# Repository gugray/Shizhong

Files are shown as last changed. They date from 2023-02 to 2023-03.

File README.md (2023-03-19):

# Remarkably Accurate Quartz Clock

This repository has all the code and design files for the Remarkably Accurate Quartz Clock
[documented on Hackaday](https://hackaday.io/project/190063-remarkably-accurate-quartz-clock).

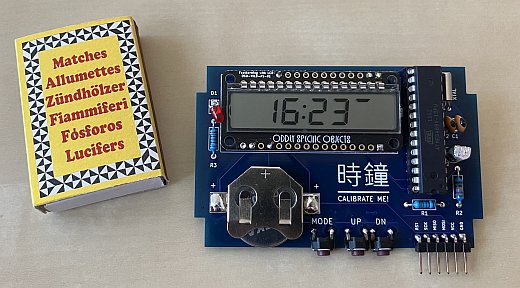
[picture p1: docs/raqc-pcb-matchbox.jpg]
The clock's circuit board, with a matchbox for scale

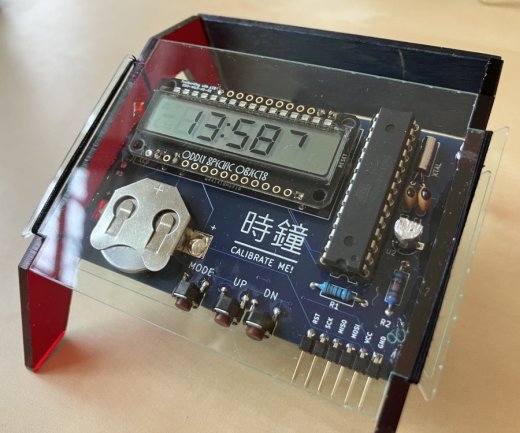
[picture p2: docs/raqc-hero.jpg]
The built-up clock in its laser-cut acrylic case


Can I use cheap, everyday components and build a quartz clock that beats specialized RTCs and matches the best commercial timepieces? Let's find out!

32kHz quartz crystals typically have a ±20ppm (parts per million) frequency tolerance, which translates to drift potentially in excess of 10 minutes per year. Specialized RTCs like DS3231 promise ±2ppm, or about ±1 minute per year.

RAQC aims for drift below 10 seconds per year. To achieve this, it implements fine-grained frequency correction in software. It has a screen to adjust time with subsecond precision, and it measures the temperature at 10-minute intervals to compensate for dynamic drift. After calibrating repeatedly at incresingly long intervals, RAQC knows the crystal's static error with a 0.01ppm precision.

Energy-saving programming techniques and a low-power LCD display keep the clock's current draw under 15μA, promising 1.5 years of uptime on a CR2032 coin cell.

## Electronics

The KiCad 5.1.9 schematic and PCB are in [/electronics](electronics). The ZIP file there is the Gerber export that I submitted to the PCB fab.

## Laser-cut frame

The frame is laser-cut from 3mm acryclic; the top and bottom covers are 1mm transparent acrylic. The front panel with the engraved overview of the clock's menu is laser-cut from 2mm birch.
The vector files for this are in [/design](design). The .ai file is the original, but I included a version re-saved as Inkscape .svg as well.

## Source code

The source code is in [/code/board](code/board). I developed it using the [PlatformIO extension](https://platformio.org/install/ide?install=vscode) for Visual Studio Code, so if you want to explore the code and build it yourself, that might be the easiest way to get started. The code uses the Arduino framework. It has only one dependency, the Wire library for I2C communication.

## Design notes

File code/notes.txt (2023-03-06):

TO-DO
=====================================
OK fine-tune by manipulating TCNT0
OK measure temp
OK faces neatly
OK periodic temp measurement
OK whole static correction shebang
   OK apply correction
   OK omit too-short time
   OK store and load from EEPROM
OK critical section around totalSeconds?
OK verify current draw
OK Fix extra beat issue in period
OK Time face: only loop function; ENTER event
OK BUG: set time screen times out on seconds
   OK timeout in seconds, not the quick timer
OK temperature-based dynamic corrections
OK design & order board v1
OK new screen on set: T0
OK don't re-measure temp on measure face
-- measure and eval green & red LED effect and current
-- battery voltage screen
?? calibration length screen?

To consider:
-- LED light button somewhere?
-- hours elapsed screen in tune face
-- do we need temperature screen? maybe midtemp calibration instead? do both fit?
-- do we need calibration history? its own screen?

Batery capacity ballpark
=====================================
CR2032 conservative capacity: 200mAh
At 50uA:  4000h, or 23 weeks
At 20uA: 10000h, or 59 weeks
At 15uA: 13333h, or 79 weeks ~ 1.5 years 
CR2: 800mAh
At 50uA: 16000h, or 95 weeks

Baseline sleep cycle, with no LCD update: 12.5uA
Spikes to ~40uA for update

Power draw with sleep to IDLE and no LCD refresh, Timer 0 as default: 400uA
Strangely, turning off Timer 0 only brings it down to 396uA
With my Timer0: 600uA

Temperature measurement
At 10 bits, DS18B20 takes 187ms -> 200ms
Active current max 1.5mA
At a 10-minute cadence: .2s out of 600s: 0.0005 mA equivalent: 0.5uA
This is not counting CPU draw during OneWire comms, but that's very quick

Experiment with 4700uF cap + 100k or 10k resistor: 14.3uA
-> this didn't catch temp measurement, so previous estimate of 0.5uA comes on top

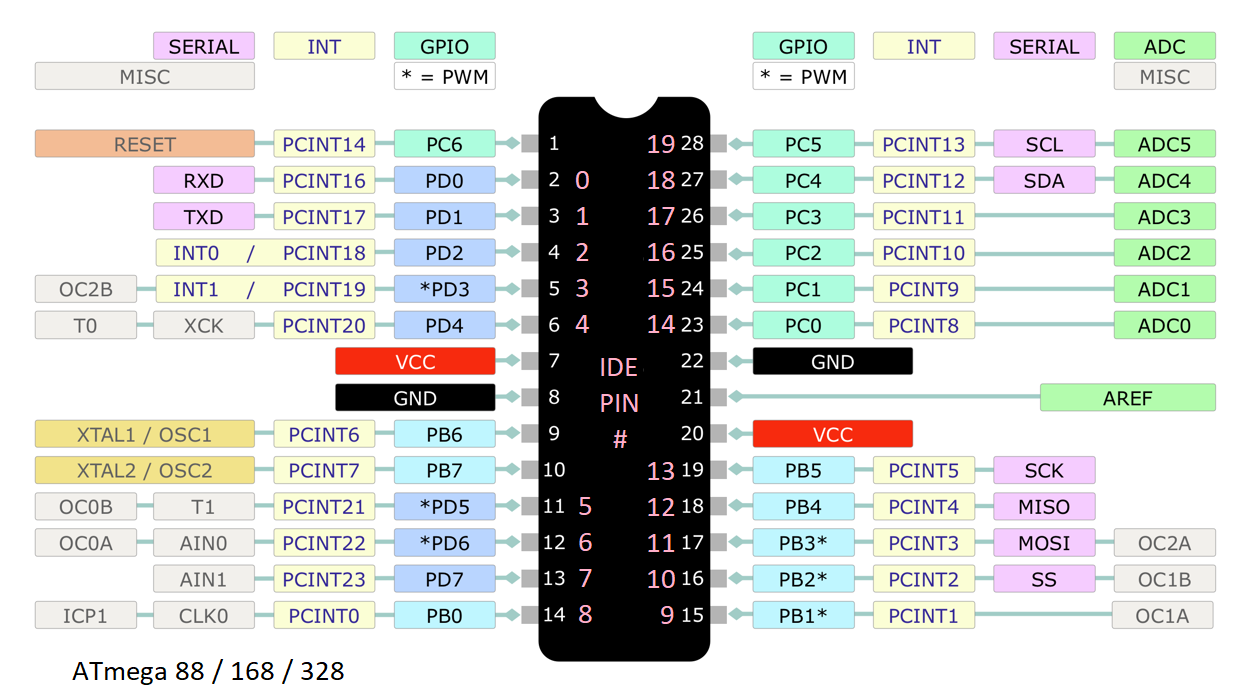
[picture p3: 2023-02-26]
docs/ATmega-88-pinout.png

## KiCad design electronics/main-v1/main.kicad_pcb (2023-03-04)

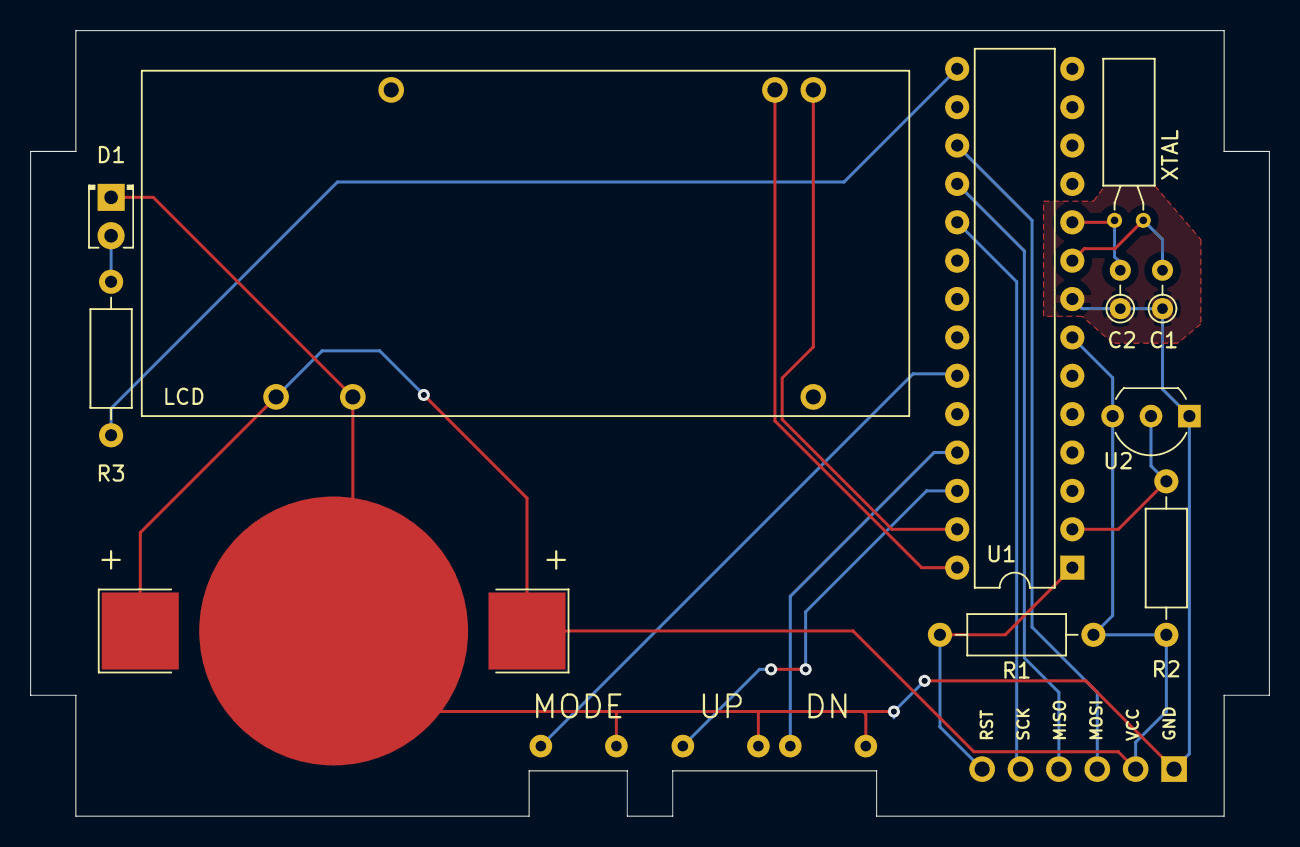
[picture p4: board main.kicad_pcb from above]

Board: 2 copper layers, 82.0 x 52.0 mm, 15 parts (0 on the bottom side), 16 nets.

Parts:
BT1: 3V Coin; BatteryHolder_Keystone_3002_1x2032
C1, C2: 6pF; R_Axial_DIN0204_L3.6mm_D1.6mm_P2.54mm_Vertical
D1: LED; LED_D2.0mm_W4.0mm_H2.8mm_FlatTop
J1: Port; PinHeader_1x06_P2.54mm_Vertical
LCD: LCD_Feather
R1: 10k; R_Axial_DIN0207_L6.3mm_D2.5mm_P10.16mm_Horizontal
R2: 5k; R_Axial_DIN0207_L6.3mm_D2.5mm_P10.16mm_Horizontal
R3: 1k; R_Axial_DIN0207_L6.3mm_D2.5mm_P10.16mm_Horizontal
SW1, SW2, SW3: SW_Push; PushButton5mm
U1: ATmega88V-10PU; DIP-28_W7.62mm
U2: DS18B20; TO-92_Inline_Wide
XTAL: 32kHz; Crystal_C38-LF_D3.0mm_L8.0mm_Horizontal

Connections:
GND: BT1.2, C1.1, C2.1, D1.1, J1.1, LCD.2, SW1.2, SW2.2, SW3.2, U1.8, U2.1
unnamed: C1.2, U1.9, XTAL.2
unnamed: C2.2, U1.10, XTAL.1
unnamed: D1.2, R3.2
unnamed: R3.1, U1.15
PIN-BTN-MINUS: SW2.1, U1.25
PIN-BTN-MODE: SW1.1, U1.23
PIN-BTN-PLUS: SW3.1, U1.26
PIN-DQ: R2.1, U1.2, U2.2
PIN-MISO: J1.4, U1.18
PIN-MOSI: J1.3, U1.17
PIN-RST: J1.6, R1.2, U1.1
PIN-SCK: J1.5, U1.19
PIN-SCL: LCD.4, U1.28
PIN-SDA: LCD.3, U1.27
VCC: BT1.1, J1.2, LCD.1, R1.1, R2.2, U1.7, U2.3

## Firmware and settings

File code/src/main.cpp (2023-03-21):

#include <Arduino.h>
#include "globals.h"
#include "events.h"
#include "DS18B20.h"
#include "persistence.h"
#include "time_face.h"
#include "tune_face.h"
#include "measure_face.h"
#include "lib/corrector.h"

// Definitions of globals vvv
// ==============================================

OSO_LCD lcd;
Time time;
Time prevTime;
uint32_t lastAdjustedAt = 0;
volatile uint32_t totalSeconds = 0;
volatile int16_t periodStartTemp = 0x7fff;
volatile int16_t latestMeasuredTemp;
volatile bool faceNeedsQuickTick = false;
volatile uint16_t counter0 = 0;
volatile uint8_t timer2Adjust = 0;
volatile uint8_t dsState = 0;

// Local vars vvv
// ==============================================

volatile uint16_t wakeEventMask = 0;
volatile uint16_t periodCounter = 0;

typedef uint8_t (*faceLoopFun)(uint16_t);

// 0: time; 1: tune; 2: measure
volatile uint8_t faceIx = 0;

const faceLoopFun loopFuns[] = {
    TimeFace::loop,
    TuneFace::loop,
    MeasureFace::loop,
};

const uint8_t nFaces = sizeof(loopFuns) / sizeof(faceLoopFun);

volatile bool timer0Running = false;
volatile uint16_t btnModePressedAt = 0xffff;
volatile uint16_t btnPlusPressedAt = 0xffff;
volatile uint16_t btnMinusPressedAt = 0xffff;

// Space for temp sensor's scratchpad
uint8_t dsData[9];

// Forward declarations of local functions vvv
// ==============================================

void stopTimer0();
void setupTimer0();
void setupTimer2();
void setupButtons();
void setupLowPower();
void goToSleep();
void configureTempSensor();
void startTempConversion();
void readTemp();

// Setup and loop: high-level control
// ==============================================

void setup()
{
  digitalWrite(LED_PIN, LOW);
  pinMode(LED_PIN, OUTPUT);

  Corrector::setStaticError(Persistence::loadStaticError());
  int16_t t0 = Persistence::loadCrystalT0();
  if (t0 != 0)
    Corrector::setCrystalT0(t0);

  lcd.begin();

  // Call time face's enter at startup, so we have meaningful content on display immediately
  loopFuns[0](EVT_ENTER_FACE);

  configureTempSensor();
  stopTimer0();
  setupButtons();
  setupTimer2();
  setupLowPower();

  dsState = 0x01; // Trigger a first temp measurement
  goToSleep();
}

void loop()
{
  uint16_t event;
  // While we handle one set of events, other interrupts might be setting other events
  while (true)
  {
    cli();
    event = wakeEventMask;
    wakeEventMask &= ~event;
    sei();
    if (event == 0)
      break;

    // In SECOND_TICK, handle temp conversion if requested
    if (ISEVENT(EVT_SECOND_TICK))
    {
      // Conversion requested now, and none in progress yet
      if (dsState == 0x01)
      {
        startTempConversion();
        dsState &= ~0x01;
        dsState |= 0x02;
      }
      // Conversion in progress: finish it!
      else if ((dsState & 0x02) != 0)
      {
        readTemp();
        dsState &= ~0x02;
      }
    }

    uint8_t ret = loopFuns[faceIx](event);
    if (ret == RET_NEXT)
    {
      faceIx = (faceIx + 1) % nFaces;
      loopFuns[faceIx](EVT_ENTER_FACE);
    }
    else if (ret == RET_HOME)
    {
      faceIx = 0;
      loopFuns[faceIx](EVT_ENTER_FACE);
    }
    if (faceNeedsQuickTick)
      setupTimer0();
  }
  goToSleep();
}

// All the machinery
// ==============================================

void setupLowPower()
{
  // For low power in sleep:
  // Disable BOD: Fuses do this
  // Disable ADC
  ADCSRA = 0;
  // Disable WDT
  cli();
  asm("WDR");
  MCUSR &= ~(1 << WDRF);
  WDTCSR |= (1 << WDCE) | (1 << WDE);
  WDTCSR = 0x00;
  sei();
}

void setupTimer2()
{
  TCCR2B = 0;        // stop Timer 2
  TIMSK2 = 0;        // disable Timer 2 interrupts
  ASSR = (1 << AS2); // select asynchronous operation of Timer 2

  // wait for TCN2UB and TCR2BUB to be cleared
  while (ASSR & ((1 << TCN2UB) | (1 << TCR2BUB)))
    ;

  TCNT2 = 0;                          // clear Timer 2 counter
  TCCR2A = (1 << WGM21);              // clear timer on compare match, no port output
  TCCR2B = (1 << CS21) | (1 << CS22); // prescaler 256, interrupt enabled

  // wait for TCN2UB and TCR2BUB to be cleared
  while (ASSR & ((1 << TCN2UB) | (1 << TCR2BUB)))
    ;

  TIFR2 = 1 << OCF2A;   // clear compare match A flag
  OCR2A = 127;          // reaches 128 once per second
  TIMSK2 = 1 << OCIE2A; // enable compare match interrupt
}

ISR(TIMER2_COMPA_vect)
{
  // Shorten or lengthen second if requested
  bool advanceTime = true; // When adding extra beats, we'll only increase second in the next interrupt
  if (timer2Adjust != 0)
  {
    // Note about fine adjustments by messing with counter
    // To turn this into a 4-times-per-second timer, this is needed (verified):
    // TCNT2 = 127 - (32 - 1);
    // When setting a low counter value to shorten a second, the following
    // turns this in to twice-per-second timer (verified):
    // TCNT2 = 64

    // If value is negative: our time is ahead: we're adding an extra delay before incrementing seconds
    if (timer2Adjust < 0)
    {
      TCNT2 = 127 + timer2Adjust + 1;
      advanceTime = false;
    }
    // Value is positive: our time is behind: we make next cycle shorter
    else
    {
      TCNT2 = timer2Adjust;
    }
    timer2Adjust = 0;
  }

  if (!advanceTime)
    return;

  // Update time
  prevTime = time;
  time.tick();
  ++totalSeconds;

  // Tell the main loop we have a TICK
  wakeEventMask |= EVT_SECOND_TICK;

  // Every measured 10 minutes, measure temperature, and apply static and dynamic frequency corrections
  // Kick off conversion two ticks before period's end
  periodCounter = (periodCounter + 1) % 600;
  if (periodCounter == PERIOD_SECONDS - 2)
  {
    // 0x01 will kick off a conversion in main loop, which will finish one tick later
    dsState = 0x01;
  }
  // At the period's start we have the new temperature. Do the frequency correction stuff now.
  else if (periodCounter == 0)
  {
    timer2Adjust += Corrector::periodUpdate((periodStartTemp + latestMeasuredTemp) / 2);
    periodStartTemp = latestMeasuredTemp;
  }
}

void goToSleep()
{
  // Disable TWI
  TWCR = bit(TWEN) | bit(TWIE) | bit(TWEA) | bit(TWINT);

  // set sleep mode: power save by default, but only idle if timer0 is alive
  if (timer0Running)
    SMCR = 0;
  else
    SMCR = (1 << SM1) + (1 << SM0);

  cli();
  SMCR |= (1 << SE); // enable sleep
  sei();
  asm("SLEEP");

  // When back: disable sleep
  SMCR &= ~(1 << SE);
}

void updateOneButton(volatile uint16_t *pressedAt, uint8_t pin, uint16_t downEventFlag)
{
  // Button is currently pressed
  if (digitalRead(pin) == LOW)
  {
    // Not pressed before
    if (*pressedAt == 0xffff)
    {
      *pressedAt = counter0;
      wakeEventMask |= downEventFlag; // DOWN
    }
    // Was already pressed
    else
    {
      uint16_t elapsed = counter0 - *pressedAt;
      // This is a long press: send once
      if (elapsed == LONG_PRESS_TICKS)
      {
        wakeEventMask |= (downEventFlag << 3); // LONG
        // This is also the first repeat
        wakeEventMask |= (downEventFlag << 1); // REPEAT
      }
      else if (elapsed > LONG_PRESS_TICKS && (elapsed - LONG_PRESS_TICKS) % REPEAT_TICKS == 0)
      {
        wakeEventMask |= (downEventFlag << 1); // REPEAT
      }
    }
  }
  // Button is currently not pressed
  else
  {
    // Was pressed before
    if (*pressedAt != 0xffff)
    {
      // Was it a short press?
      // In the other case, we will have sent out a long press event before
      if (counter0 - *pressedAt < LONG_PRESS_TICKS)
        wakeEventMask |= (downEventFlag << 2); // SHORT
    }
    *pressedAt = 0xffff;
  }
}

bool updateButtons()
{
  updateOneButton(&btnModePressedAt, BTN_MODE_PIN, EVT_BTN_MODE_DOWN);
  updateOneButton(&btnPlusPressedAt, BTN_PLUS_PIN, EVT_BTN_PLUS_DOWN);
  updateOneButton(&btnMinusPressedAt, BTN_MINUS_PIN, EVT_BTN_MINUS_DOWN);

  // Quit timer if no button is pressed
  return btnModePressedAt == 0xffff && btnPlusPressedAt == 0xffff && btnMinusPressedAt == 0xffff;
}

void setupButtons()
{
  pinMode(BTN_MODE_PIN, INPUT_PULLUP);
  pinMode(BTN_PLUS_PIN, INPUT_PULLUP);
  pinMode(BTN_MINUS_PIN, INPUT_PULLUP);
  PCMSK1 |= bit(PCINT11) | bit(PCINT10) | bit(PCINT8);
  PCIFR |= bit(PCIF1);
  PCICR |= bit(PCIE1);
}

void stopTimer0()
{
  timer0Running = false;
  TCCR0B = 0; // Stop Timer 0
  TIMSK0 = 0; // Disable Timer 0 interrupts
  counter0 = 0;
}

void setupTimer0()
{
  if (timer0Running == true)
    return;

  counter0 = 0;
  timer0Running = true;
  TCNT0 = 0;                          // clear Timer 2 counter
  TCCR0A = (1 << WGM01);              // clear timer on compare match, no port output
  TCCR0B = (1 << CS02) | (1 << CS00); // prescaler 1024, interrupt enabled.
                                      // This is from 1 MHz CPU clock! CPU *must* be at 1 MHz.
                                      // 1MHz / 1024 = 976.5625
  TIFR0 = 1 << OCF0A;                 // clear compare match A flag
  OCR0A = 19;                         // reaches 20 about 50x per second
  TIMSK0 = 1 << OCIE0A;               // enable compare match interrupt
}

ISR(TIMER0_COMPA_vect)
{
  ++counter0;
  bool stopTimer = updateButtons();
  // Faces that need the quick tick
  if (stopTimer && !faceNeedsQuickTick)
    stopTimer0();
  wakeEventMask |= EVT_QUICK_TICK;
}

ISR(PCINT1_vect)
{
  // If timer 0 is not running, start it
  // We'll be reading button state in interrupt handler
  setupTimer0();
}

void configureTempSensor()
{
  cli();
  DS18B20::reset();
  DS18B20::write(0xCC); // Skip ROM
  DS18B20::write(0x4E); // Write scratchpad
  DS18B20::write(0x00); // TH: unused
  DS18B20::write(0x00); // TL: unused
  DS18B20::write(0x20); // Config register for 10-bit resolution (gives us .25C)
  sei();
}

void startTempConversion()
{
  cli();
  DS18B20::reset();
  DS18B20::write(0xCC); // Skip ROM
  DS18B20::write(0x44); // Start convesion
  sei();
}

void readTemp()
{
  cli();
  DS18B20::reset();
  DS18B20::write(0xCC); // Skip ROM
  DS18B20::write(0xBE); // Read scratchpad
  for (uint8_t i = 0; i < 9; i++)
    dsData[i] = DS18B20::read();
  sei();
  // Convert the data to actual temperature
  int16_t raw = (dsData[1] << 8) | dsData[0];
  // Zero out lowest two bits, we're using 10-bit resolution
  raw = raw & ~3;
  // This is temp Celsius * 20
  latestMeasuredTemp = raw * 5 / 4;
  // Very first time we measure, set period start temperature too
  // Later on this is Timer2's job (so interim user-triggered measurements don't overwrite it)
  if (periodStartTemp == 0x7fff)
    periodStartTemp = latestMeasuredTemp;
}

uint32_t safeGetTotalSeconds()
{
  uint32_t res;
  cli();
  res = totalSeconds;
  sei();
  return res;
}

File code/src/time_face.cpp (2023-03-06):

#include <Arduino.h>
#include "time_face.h"
#include "events.h"
#include "globals.h"

// 0: time; 1: set hour; 2: set minute; 3: set second
static uint8_t screen;
static uint8_t buf[7];
static uint8_t blinkCounter;
static uint16_t timeoutStart;

static void resetTimeout();

static void drawTime(bool forceRedraw);
static void drawSetTime();
static void resetSecond();

uint8_t TimeFace::loop(uint16_t event)
{
  if (ISEVENT(EVT_ENTER_FACE))
  {
    screen = 0;
    drawTime(true);
    return RET_STAY;
  }

  // Events on time screen
  // ----------------------------------
  if (screen == 0)
  {
    if (ISEVENT(EVT_SECOND_TICK))
      drawTime(false);
    if (ISEVENT(EVT_BTN_MODE_LONG))
    {
      screen = 1;
      faceNeedsQuickTick = true;
      blinkCounter = 0;
      resetTimeout();
    }
    if (ISEVENT(EVT_BTN_MODE_SHORT))
    {
      return RET_NEXT;
    }
    return RET_STAY;
  }

  // Events on set screens from here on
  // ----------------------------------


  if (ISEVENT(EVT_BTN_MODE_SHORT) || ISEVENT(EVT_BTN_MODE_LONG))
  {
    resetTimeout();
    screen = (screen + 1) % 4;
    if (screen == 0)
    {
      drawTime(true);
      faceNeedsQuickTick = false;
    }
    return RET_STAY;
  }
  if (ISEVENT(EVT_QUICK_TICK))
  {
    blinkCounter = (blinkCounter + 1) % BLINK_PERIOD;
  }
  if (ISEVENT(EVT_SECOND_TICK))
  {
    uint16_t elapsed = (totalSeconds & 0xffff) - timeoutStart;
    if (elapsed > TIMEOUT_SECONDS)
    {
      screen = 0;
      drawTime(true);
      faceNeedsQuickTick = false;
      return RET_STAY;
    }
  }

  if (ISEVENT(EVT_BTN_MINUS_DOWN) || ISEVENT(EVT_BTN_MINUS_REPEAT))
  {
    resetTimeout();
    cli();
    if (screen == 1)
      time.hour = time.hour == 0 ? 23 : time.hour - 1;
    else if (screen == 2)
      time.min = time.min == 0 ? 59 : time.min - 1;
    else
      resetSecond();
    blinkCounter = BLINK_PERIOD / 2;
    sei();
  }
  if (ISEVENT(EVT_BTN_PLUS_DOWN) || ISEVENT(EVT_BTN_PLUS_REPEAT))
  {
    resetTimeout();
    cli();
    if (screen == 1)
      time.hour = (time.hour + 1) % 24;
    else if (screen == 2)
      time.min = (time.min + 1) % 60;
    else
      resetSecond();
    blinkCounter = BLINK_PERIOD / 2;
    sei();
  }
  drawSetTime();
  return RET_STAY;
}

static void resetTimeout()
{
    timeoutStart = (totalSeconds & 0xffff);
}

static void resetSecond()
{
  time.sec = 0;
  TIFR2 = 1 << OCF2A; // clear compare match A flag
  TCNT2 = 0;          // clear Timer 2 counter

  // If we mess with seconds here, can't calibrate the next time in tune_face
  lastAdjustedAt = 0;
}

static void drawTime(bool forceRedraw)
{
  bool minChanged = forceRedraw || time.min != prevTime.min;
  bool quartMinChanged = forceRedraw || time.sec / 15 != prevTime.sec / 15;

  // Update full time if minute has changed
  // Could save some more updating, but because colon is at start of buffer,
  // and we'll change last two digits, partial update would no longer be cheaper anyway.
  if (minChanged)
  {
    uint8_t hourLo = time.hour % 10;
    uint8_t hourHi = time.hour / 10;
    uint8_t minLo = time.min % 10;
    uint8_t minHi = time.min / 10;
    if (hourHi == 0)
      lcd.buffer[2] = 0;
    else
      lcd.buffer[2] = digits[hourHi];
    lcd.buffer[3] = digits[hourLo];
    lcd.buffer[4] = digits[minHi];
    lcd.buffer[5] = digits[minLo];
  }

  // Last digit: quarter-minute circle at top
  if (quartMinChanged)
  {
    uint8_t q = time.sec / 15;
    uint8_t secVal = 0b10000000; // top
    if (q >= 1)
      secVal |= 0b00001000;
    if (q >= 2)
      secVal |= 0b00000010;
    if (q >= 3)
      secVal |= 0b01000000;
    lcd.buffer[6] = secVal;
  }

  // Colon on/off
  lcd.buffer[1] = ((time.sec % 2) == 0) ? OSO_INDICATOR_COLON : 0;

  // Update the least we can
  if (!minChanged)
  {
    // Update colon
    lcd.show_partial(1, 1);
    // Less often, update seconds symbol too
    if (quartMinChanged)
      lcd.show_partial(6, 1);
  }
  // Minute has changed: update whole display
  else
    lcd.show();
}

static void drawSetTime()
{
  // "Draw" into new buffer
  memset(buf, 0, 7);

  // Setting hours or minutes
  if (screen != 3)
  {
    // Draw hours
    if (screen != 1 || (screen == 1 && blinkCounter >= BLINK_PERIOD / 2))
    {
      if (time.hour >= 10)
        buf[2] = digits[time.hour / 10];
      buf[3] = digits[time.hour % 10];
    }
    // Draw minutes
    if (screen != 2 || (screen == 2 && blinkCounter >= BLINK_PERIOD / 2))
    {
      buf[4] = digits[time.min / 10];
      buf[5] = digits[time.min % 10];
    }
    // Colon on/off
    buf[1] = ((time.sec % 2) == 0) ? OSO_INDICATOR_COLON : 0;
  }
  // Setting seconds
  else
  {
    // Minutes on the left
    buf[2] = digits[time.min / 10];
    buf[3] = digits[time.min % 10];
    // Seconds on the right, unless blinked hidden
    if (blinkCounter >= BLINK_PERIOD / 2)
    {
      buf[5] = digits[time.sec / 10];
      buf[6] = digits[time.sec % 10];
    }
    // With decimal digit in front
    buf[5] |= OSO_SYMBOL_DOT;
  }

  // Flush if different
  if (memcmp(buf, lcd.buffer, 7) != 0)
  {
    memcpy(lcd.buffer, buf, 7);
    lcd.show();
  }
}

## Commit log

2023-02-27 buttons handled
2023-02-28 auto match counter recent - timer2 usage cleaner this way
2023-02-28 debounced buttons + quick tick thru timer 0
2023-03-03 temperature's working!
2023-03-04 two board variants
    [main.kicad_pcb, main.sch]
2023-03-05 nah formula was right, just can't insert a single extra beat at a time
2023-03-06 fix: extra tick in next period when second was lengthened
    [globals.h, main.cpp]
2023-03-06 application note about calibration of STM32
2023-03-19 LED pin change for final PCB
2023-03-19 cleanup: electronics files
    [main.kicad_pcb, main.sch]
2023-03-19 design files for laser-cut case
2023-03-19 add pcb image
2023-03-19 update pcb image
